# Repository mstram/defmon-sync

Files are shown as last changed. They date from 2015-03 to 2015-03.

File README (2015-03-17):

defMon Sync Adapter is an adapter for the Commodore 64 computer. It is used to synchronize a tracker called defMon with other music equipment. It connects to the user port and outputs the following signals:
-LSDJ sync signal.
-nanoloop sync signal.
-midi clock.
-din sync.
-clock signal with adjustable resolution from 24ppqn to 2ppqn for Korg Volcas, TE Pocket Operators, Arturia Microbrute, MI Anushri etc.
It can only work as master.
It should also work with Prophet64.

Original developer: Krzysztof Iwanowski

The firmware, PCB layouts and schematics are released under a Creative Commons cc-by-sa 3.0 license.

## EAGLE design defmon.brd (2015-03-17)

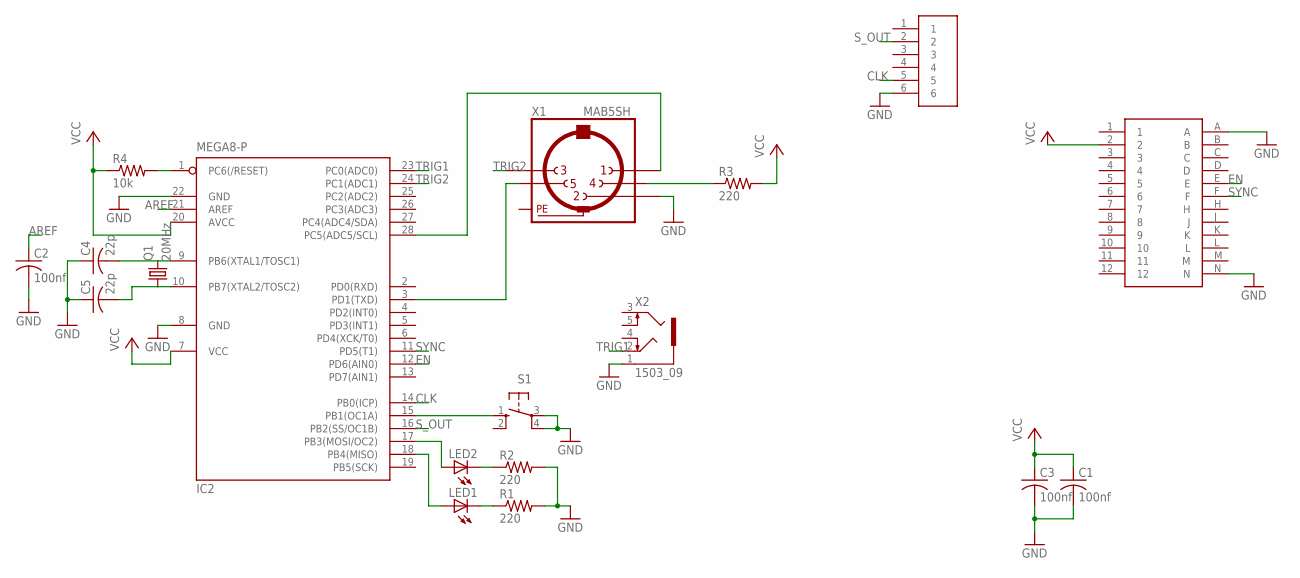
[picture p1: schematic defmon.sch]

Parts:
C1, C2, C3: 100nf; C025-025X050
C4, C5: 22p; C025-025X050
IC2: MEGA8-P; DIL28-3
LED1, LED2: LED3MM
Q1: 20MHz; HC49U-V
R1, R2, R3: 220; 0204/7
R4: 10k; 0204/7
S1: 40-XX; B3F-40XX
U$1: GB
U$2: C64U
X1: MAB5SH
X2: 1503_09

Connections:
AREF: C2.1, IC2.21 (AREF)
CLK: IC2.14 (PB0(ICP)), U$1.5
EN: IC2.12 (PD6(AIN0)), U$2.E
GND: C1.2, C2.2, C3.2, C4.1, C5.1, IC2.8 (GND), IC2.22 (GND), R1.2, R2.2, S1.3, S1.4 (P1), U$1.6, U$2.A, U$2.N, X1.2, X2.1
unnamed: LED2.K (C), R2.1
unnamed: LED1.K (C), R1.1
unnamed: R3.1, X1.4
unnamed: IC2.15 (PB1(OC1A)), S1.1 (S)
unnamed: IC2.17 (PB3(MOSI/OC2)), LED2.A
unnamed: IC2.18 (PB4(MISO)), LED1.A
unnamed: C4.2, IC2.9 (PB6(XTAL1/TOSC1)), Q1.2
unnamed: IC2.28 (PC5(ADC5/SCL)), X1.1
unnamed: C1.1, C3.1, IC2.7 (VCC), IC2.20 (AVCC), R3.2, R4.1, U$2.2
unnamed: C5.2, IC2.10 (PB7(XTAL2/TOSC2)), Q1.1
unnamed: IC2.1 (PC6(/RESET)), R4.2
unnamed: IC2.3 (PD1(TXD)), X1.5
PE: X1.PE, X1.PE@ (PE)
SYNC: IC2.11 (PD5(T1)), U$2.F
S_OUT: IC2.16 (PB2(SS/OC1B)), U$1.2
TRIG1: IC2.23 (PC0(ADC0)), X2.2
TRIG2: IC2.24 (PC1(ADC1)), X1.3

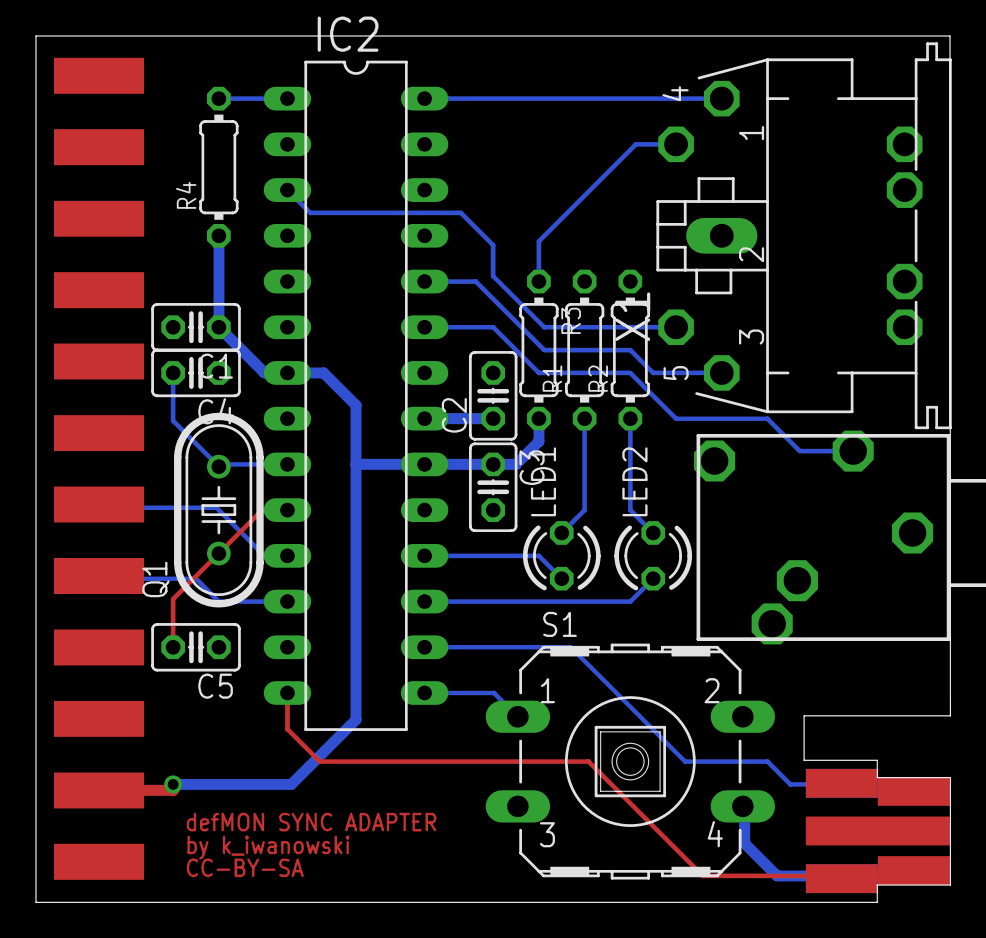
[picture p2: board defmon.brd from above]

Board: 2 copper layers, 50.8 x 48.1 mm, 18 parts (0 on the bottom side), 21 nets.

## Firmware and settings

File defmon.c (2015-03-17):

#define F_CPU 20000000L

#define USART_BAUDRATE 31250
#define BAUD_PRESCALE (((F_CPU / (USART_BAUDRATE * 16UL))) - 1)

#include <avr/io.h>
#include <avr/eeprom.h>
#include <util/delay.h>
#include <stdbool.h>

int main(void) {

	int LED_pin = 3, button_pin = 1, blink_counter = 0, i, div1 = 0, divtab[4] = {1,3,6,12}, counter3;
	long hold_counter = 0, blink_counter2 = 0, div2;
	bool gb_mode = true, sync, state = true, button_state = true, button, nano = true, midi_state = true, div_state = false, button_state2, start = true;

	DDRB |= _BV(3)|_BV(4)|_BV(0)|_BV(2); // led pins as outputs; gb pins as outputs (0 - lsdj, 2 - nl)
	DDRB &= ~_BV(button_pin); // button pin as input
	DDRC |= _BV(0)|_BV(1)|_BV(5); // sync24out pin as output (0,1 - sync, 5 - en)
	DDRD &= ~(_BV(5)|_BV(6)); // sync24in pins as inputs (5 - sync, 6 - en)
	PORTB |= _BV(button_pin); // internal pullup on the button input
	PORTB |= _BV(LED_pin); //led on

	UCSR0B = (1 << TXEN0);
	UCSR0C = (1 << UCSZ00) | (1 << UCSZ01);
	UBRR0H = (BAUD_PRESCALE >> 8);
	UBRR0L = BAUD_PRESCALE;

	while (1) { 
		if (start) {
			while (!eeprom_is_ready()); 
			counter3 = eeprom_read_byte(0);
			if (counter3 != 1 && counter3 != 3 && counter3 != 6 && counter3 != 12) counter3 = 1;
			div2 = counter3;
			start = false;
			}
		button = PINB & _BV(button_pin); 
		if (!button && button_state) { 
			gb_mode = !gb_mode;
			button_state = false;
			button_state2 = true;
			if (LED_pin == 3) {
				PORTB &= ~_BV(LED_pin);
				LED_pin = 4;
				PORTB |= _BV(LED_pin);
                }
			else {
				PORTB &= ~_BV(LED_pin);
				LED_pin = 3;
				PORTB |= _BV(LED_pin);
				}
			_delay_ms(10);
			}
		if (button && !button_state) {
			button_state = true;
			hold_counter = 0;
			_delay_ms(10);
			}
		if (!button_state && button_state2) {
			hold_counter++;
			if (hold_counter > 500000) {
				div_state = true;
				hold_counter = 0;
				button_state2 = false;
				}
			while(div_state) {
				blink_counter2++;
				if (blink_counter2 > div2 * 8000) {
						blink_counter2 = 0;
						if (LED_pin == 3) {
							PORTB &= ~_BV(LED_pin);
							LED_pin = 4;
							PORTB |= _BV(LED_pin);
							}
						else {
							PORTB &= ~_BV(LED_pin);
							LED_pin = 3;
							PORTB |= _BV(LED_pin);
							}
						}
				button = PINB & _BV(button_pin); 
				if (!button && button_state) {
					button_state = false;
					div1++;
					if(div1 > 3) div1 = 0;
					div2 = divtab[div1];
					counter3 = div2;
					button_state2 = true;
					_delay_ms(10);
					}
				if (button && !button_state) {
					button_state = true;
					hold_counter = 0;
					_delay_ms(10);
					}
				if (!button_state && button_state2) {
					hold_counter++;
					if (hold_counter > 500000) {
						while (!eeprom_is_ready());
						eeprom_update_byte(0, counter3);
						div_state = false;
						hold_counter = 0;
						button_state2 = false;
						}
					}	
					
				}
			}
			
  
		if (PIND & _BV(6)) {
			if (midi_state) {
				while (!(UCSR0A & (1<<UDRE0))); // Do nothing until UDR is ready for more data to be written to it
				UDR0 = 0xFA; // Send out the byte value in the variable "ByteToSend"
				PORTC |= _BV(5); // sync24 en out on
				midi_state = false;
				}
			sync = PIND & _BV(5);
			if (sync && state) {
				if (gb_mode) {
					PORTB &= ~_BV(2);
					for(i = 0; i < 8; i ++) {
						PORTB &= ~_BV(0);
						_delay_us(60);
						PORTB |= _BV(0);
						}
					}
				else {
					if (nano) PORTB |= _BV(2);
					else PORTB &= ~_BV(2);
					nano = !nano;
					}

				while (!(UCSR0A & (1<<UDRE0))); // Do nothing until UDR is ready for more data to be written to it
				UDR0 = 0xF8; // Send out the byte value in the variable "ByteToSend"
					
				if (counter3 == div2) {
					PORTC |= _BV(0); // sync24 sync out high
					counter3 = 0;
					}
					counter3++;
				PORTC |= _BV(1); // sync24 sync out high
				_delay_ms(5);
				PORTC &= ~_BV(0); // sync24 sync out low
				PORTC &= ~_BV(1); // sync24 sync out low
	  
				state = false;
				blink_counter++;
				if (blink_counter == 6) {
					PORTB |= _BV(LED_pin);
					blink_counter = 0;
					}
					else PORTB &= ~_BV(LED_pin);
				}
			if (!sync && !state) state = true;
			}
		else {
			if (!midi_state) {
				while (!(UCSR0A & (1<<UDRE0))); // Do nothing until UDR is ready for more data to be written to it
				UDR0 = 0xFC; // Send out the byte value in the variable "ByteToSend"
				blink_counter = 0;
				PORTB &= ~_BV(2);
				PORTB |= _BV(LED_pin);
				nano = true;
				state = true;
				PORTC &= ~_BV(5); // sync en out off
				midi_state = true;
				counter3 = div2;
				}
			}
		}
	}
